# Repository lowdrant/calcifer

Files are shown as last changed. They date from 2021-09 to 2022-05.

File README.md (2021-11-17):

# calcifer
Raspberry Pi Talking Fireplace

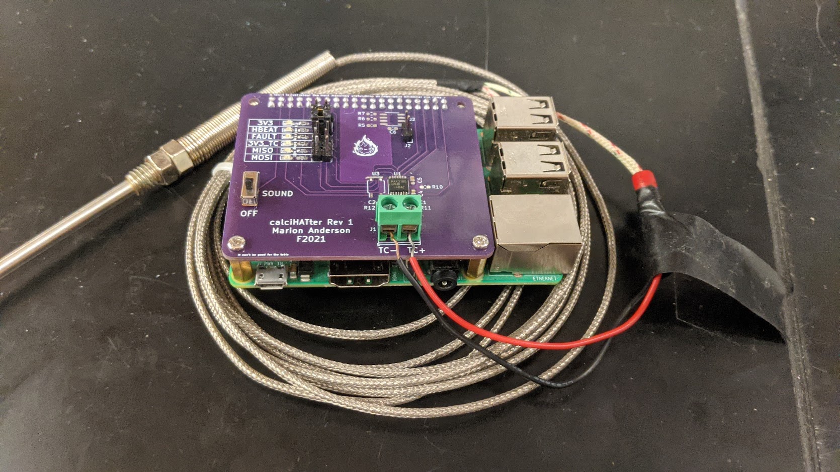
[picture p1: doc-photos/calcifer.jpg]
Calcifer


## Quick Start
1. Use AdaFruit's [MAX31856 breakout board](https://www.adafruit.com/product/3263) and a fire-resistant [thermocouple](https://www.adafruit.com/product/3245) setup.
2. Follow this [AdaFruit wiring guide](https://learn.adafruit.com/adafruit-max31856-thermocouple-amplifier/python-circuitpython) and connect `DRDY` to `Board D27` and `FAULT` to `Board D20`
3. Put the thermocouple in your fireplace
4. Connect a speaker to the RPI headphone jack
5. Run the following in the terminal:
```
> git clone https://github.com/lowdrant/calcifer.git
> sudo apt install python3-pip           # skip if pip3 installed
> cd calcifer
> ./install.sh                           # install dependencies
> sudo ./boot-setup.sh ADAFRUIT          # setup calcifer to run at boot (daemon)
> sudo systemctl start calcifer.service  # start daemon
> journatlctl -f -u calcifer.service     # stream log output
```

### Using with calciHATter PCB
calciHATter Pi HAT wiring is stored in the CALCIHATTER section of [calcifer.ini](calcifer.ini). After dependencies are installed, you only need to configure which config section Calcifer uses.
```
> sudo ./boot-setup.sh CALCIHATTER
> sudo systemctl restart calcifer.service
```

## Adding Sounds
Add .wav files to the [sounds/](sounds/) directory to add sounds for Calcifer. Calcifer plays a random .wav file from [sounds/](sounds/) when it detects a fire has started. This ensures Calcifer only plays a sound once rather than playing sounds constantly while a fire is going.

## Customizating Behavior and Pinout
[calcifer.ini](calcifer.ini) can be edited to configure entire hardware pinout and some program logic. It is parsed using Python3's `ConfigParser` object. After editing the config section the Calcifer daemon is using, run
```
> sudo systemctl restart calcifer.service
```
to reinitalize Calcifer with the new configuration. Since the config _section_ isn't changing, there's no need to resetup the daemon.

To change configuration sections (e.g. from ADAFRUIT to CALCIHATTER), run
```
> sudo ./boot-setup.sh <your-section>
```

### GPIO Configuration
GPIO values need to be of the form `board.XX` as if they are commands in a Python script because [calcifer.py](calcifer.py) uses `eval(<param>)` to configure GPIO objects. Look into CircuitPython for more details.

| Field | Desc | Example | Notes |
| --- | --- | --- | --- |
| spi | Amplifier SPI bus | board.SPI() | RPi SPI busses are weirdly specific |
| cs | Amplifier chip select | board.D22 | Digital Output |
| drdy | Amplifier data ready pin | board.D27 | Digital Input |
| tc_fault | Amplifier fault pin | board.D3 | Digital Input |
| tc_reset | Amplifier power switch pin | board.D26 | Digital Output |
| soundswitch | Toggle sound playing | board.D2 | Digital Input; play sound if high |
| hbeat | Heartbeat LED | board.D21 | Digital Output |
| fault | Fault indicator LED | board.D20 | Digital Output |

### Temperature Logic
Configure temperature sensor type, active/inactive temperature thresholds, and data reading frequency. `thresh` and `off_thresh` introduce hysterisis

| Field | Desc | Example | Notes |
| --- | --- | --- | --- |
| tctype | Thermocouple type | K | `adafruit_max31856.ThermocoupleType` |
| thresh | threshold for fire-on state | 100 | degC float |
| off_thresh | threshold for fire-off state | 50 | degC float; must be less than thresh |
| T_read | sample period in fire-off state | 1 | seconds |
| T_going | sample period in fire-on state  | 10 | seconds |

### Misc Behavior
This does not affect the user experience.
| Field | Desc | Example | Notes |
| --- | --- | --- | --- |
| host | Host for daemon stop command | 127.0.0.1 | host must be RPi |
| port | Port for daemon stop command | 10000 | |
| loglevel | log level to stdout | DEBUG | logging library value |
| drdy_count_timeout | Timeout for amp power cycle  | 3 | int |
| T_hbeat | Heartbeat period | 2 | seconds |

## Design Overview
### Hardware
The calciHATter PCB conforms to the Raspberry Pi HAT standard. It is a bare-bones PCB that allows a Pi to interface with the MAX31856 over SPI, a sound switch for enabling/disabling Calcifer, debug LEDs, and the configuration EEPROM. Its documentation, fabrication files, and bill of materials can be found in [calciHATter/](calciHATter/). It was designed in KiCAD. I do not provide a means to program the HAT EEPROM with pinout information.

### Software
The Calcifer daemon simply calls [calcifer.py](calcifer.py) with appropriate command line arguments.
[boot-setup.sh](boot-setup.sh) provides a CLI to automatically configure `calcifer.service` for SystemD.

Calcifer program logic is packaged as an object inside a CLI script to run the Calcifer mainloop in a clean, stateful way while also providing a basic testing/characterization interface for thermocouple evaluation and debugging.

The Calcifer object uses 3 threads in its mainloop
1. `_run`, which measures temperature and plays sound if fire goes from off to on
2. `_hbeat`, which blinks the heartbeat LED
3. `_listen`, which listens for a shutdown command on `host:port` and joins the mainllop threads on receipt of said shutdown command

### Fixing Sound Issues
Some PyGame dependencies need to be built from source (namely LibSDL2) for unknown reasons. `install.sh` should handle this, but if you are still getting sound issues, run the below to install the dependencies directly.
```
> ./install-pygame-deps.sh
```

## Author
Marion Anderson - [lmanderson42@gmail.com](mailto:lmanderson42@gmail.com)

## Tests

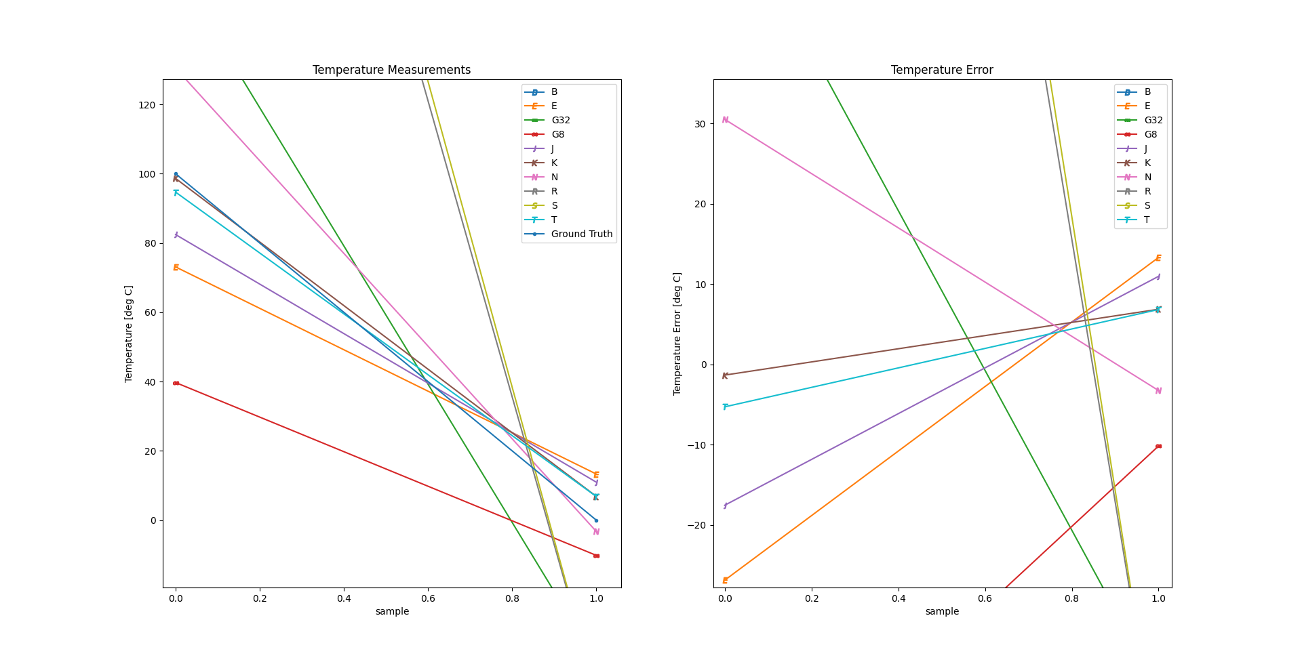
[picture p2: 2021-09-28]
tc-characterization.png

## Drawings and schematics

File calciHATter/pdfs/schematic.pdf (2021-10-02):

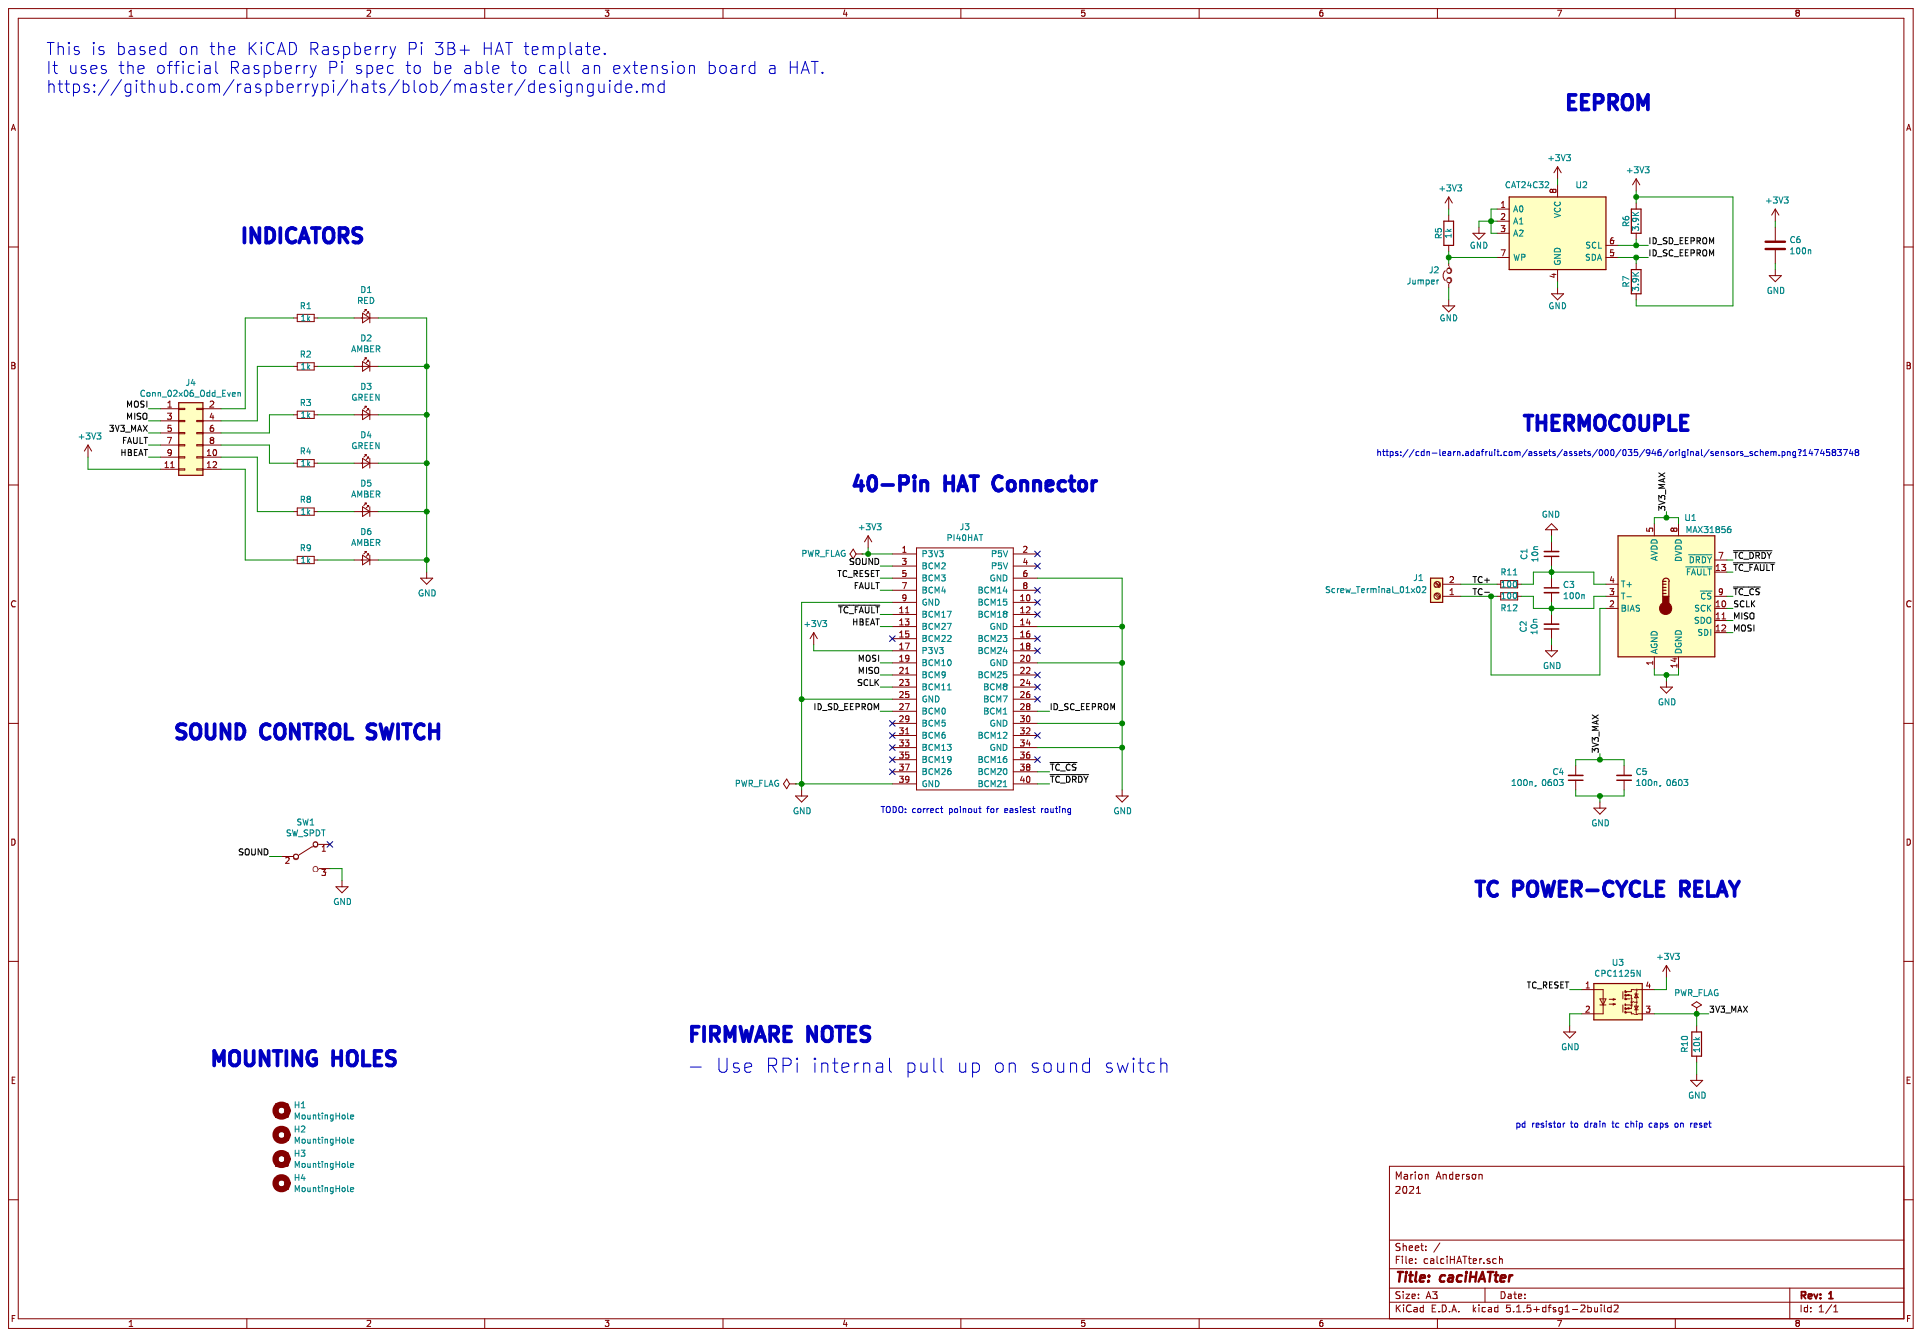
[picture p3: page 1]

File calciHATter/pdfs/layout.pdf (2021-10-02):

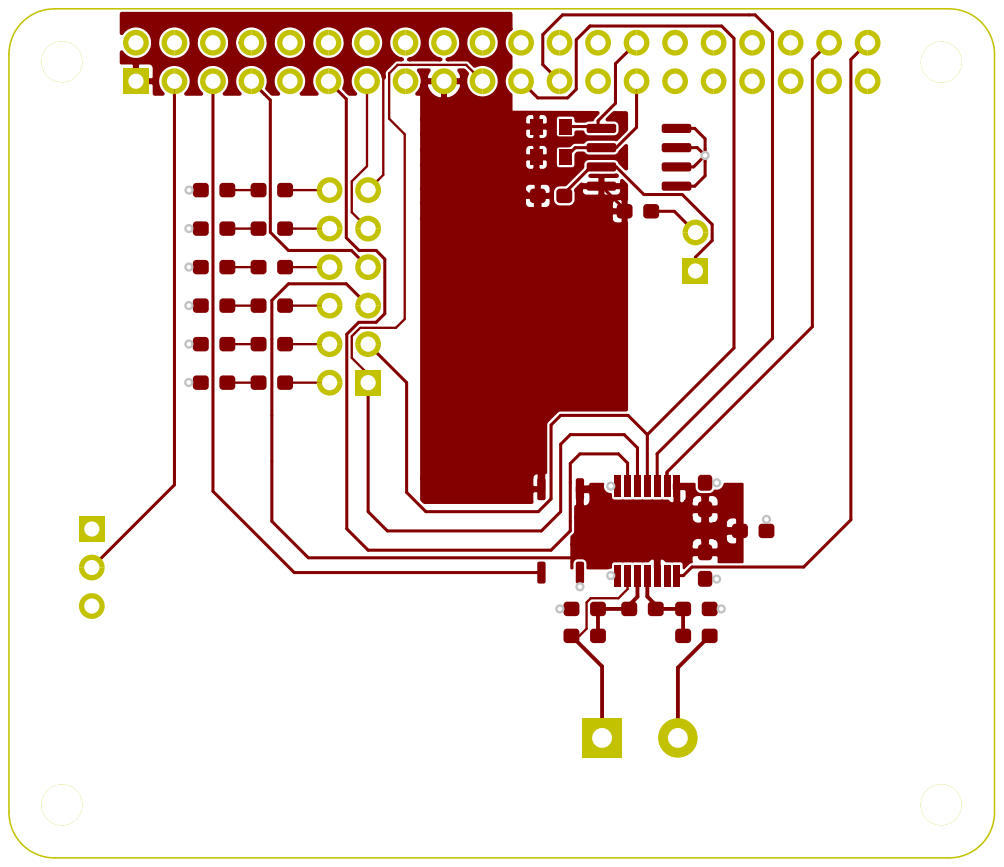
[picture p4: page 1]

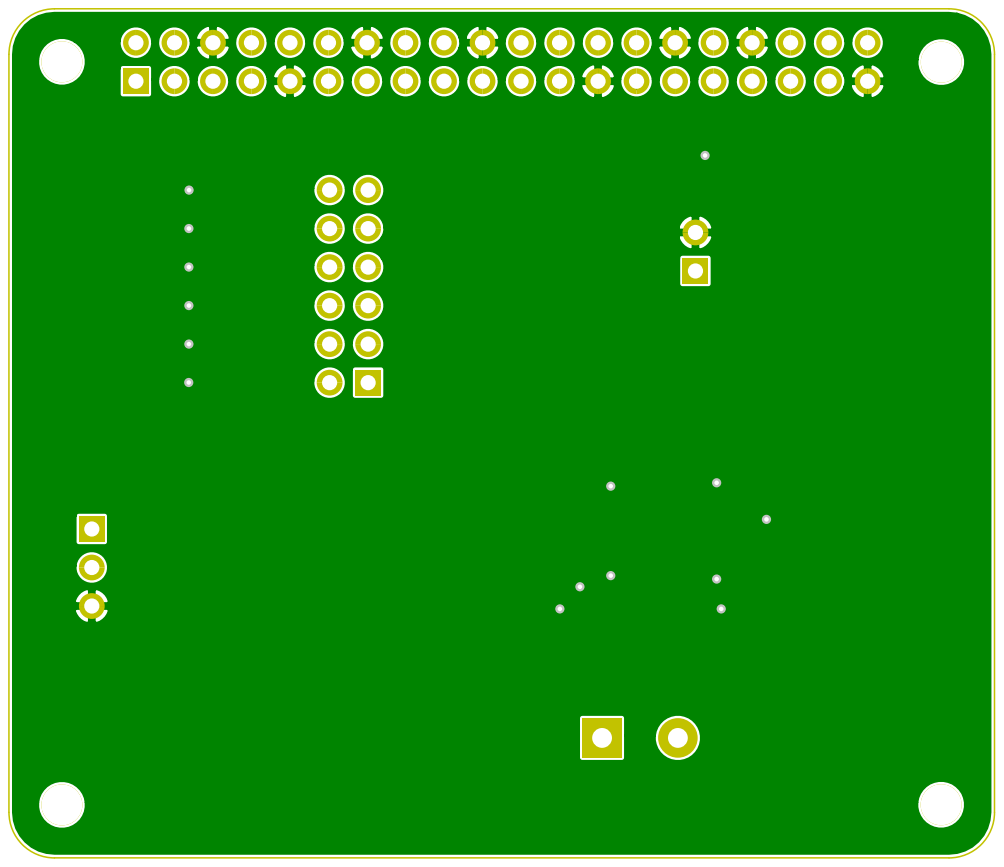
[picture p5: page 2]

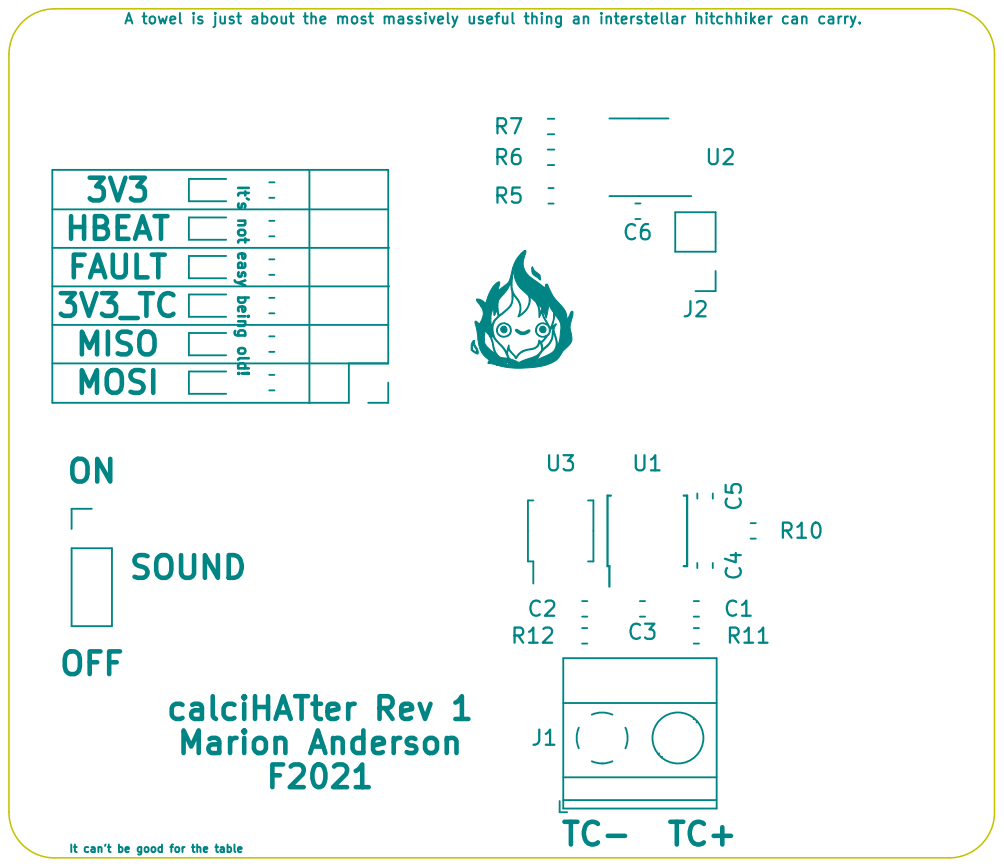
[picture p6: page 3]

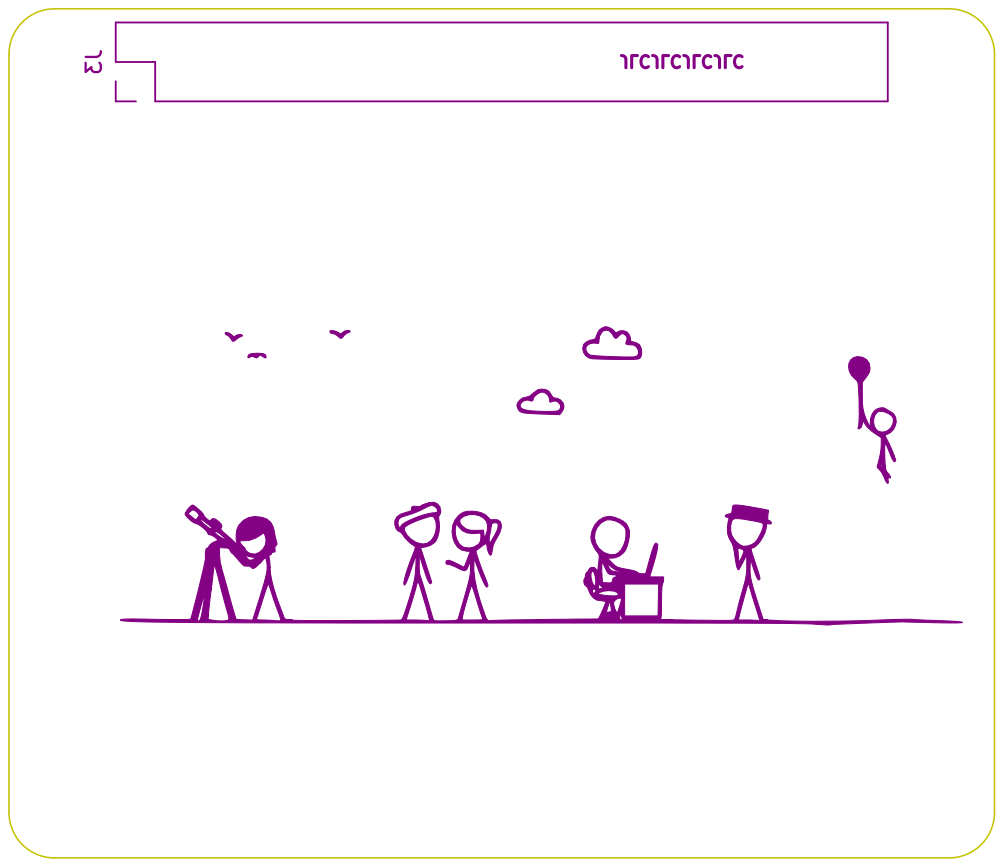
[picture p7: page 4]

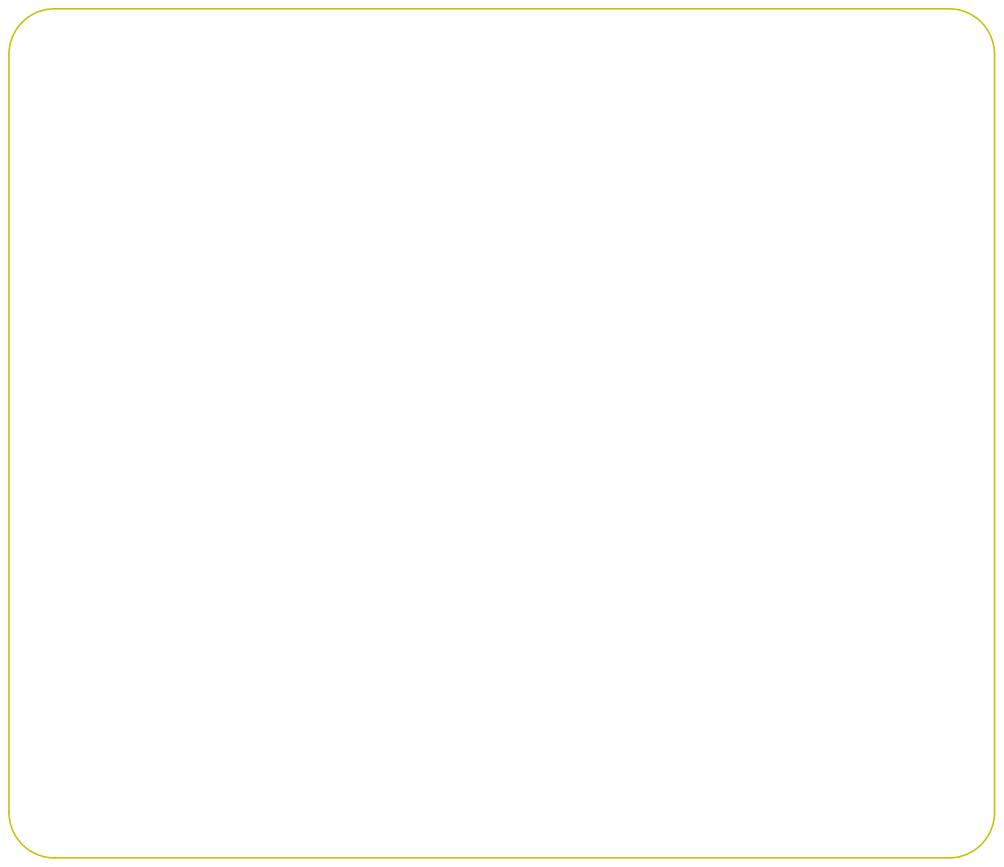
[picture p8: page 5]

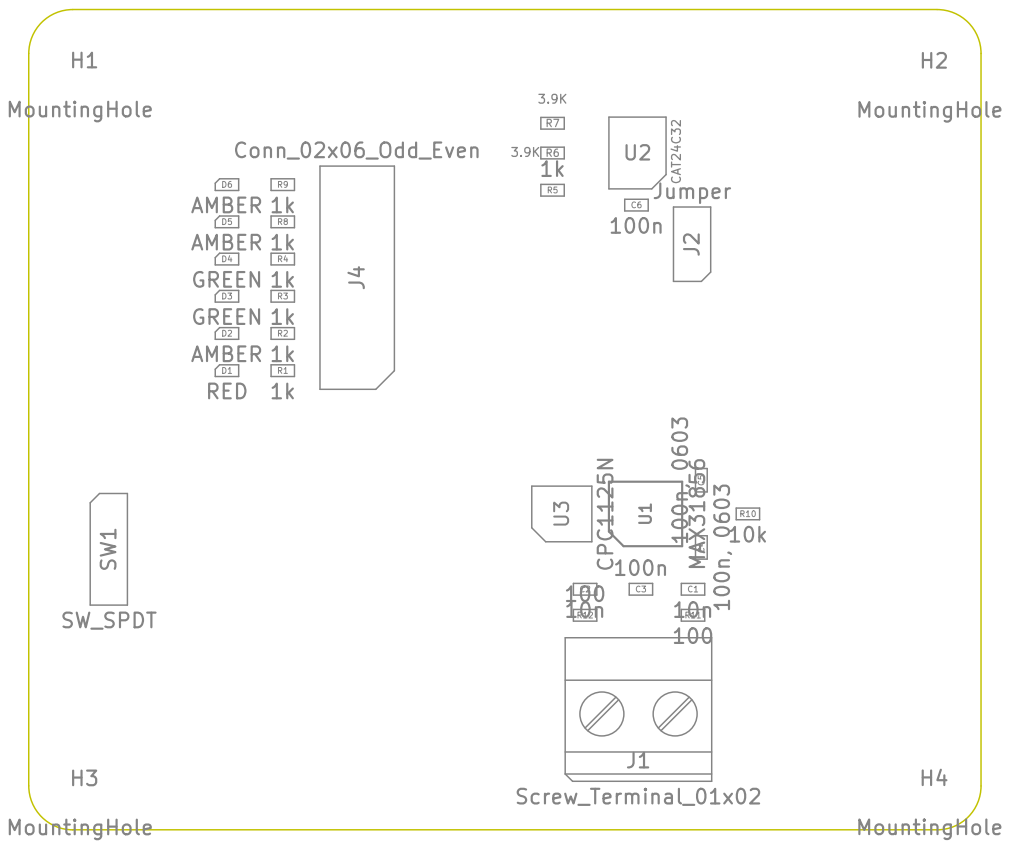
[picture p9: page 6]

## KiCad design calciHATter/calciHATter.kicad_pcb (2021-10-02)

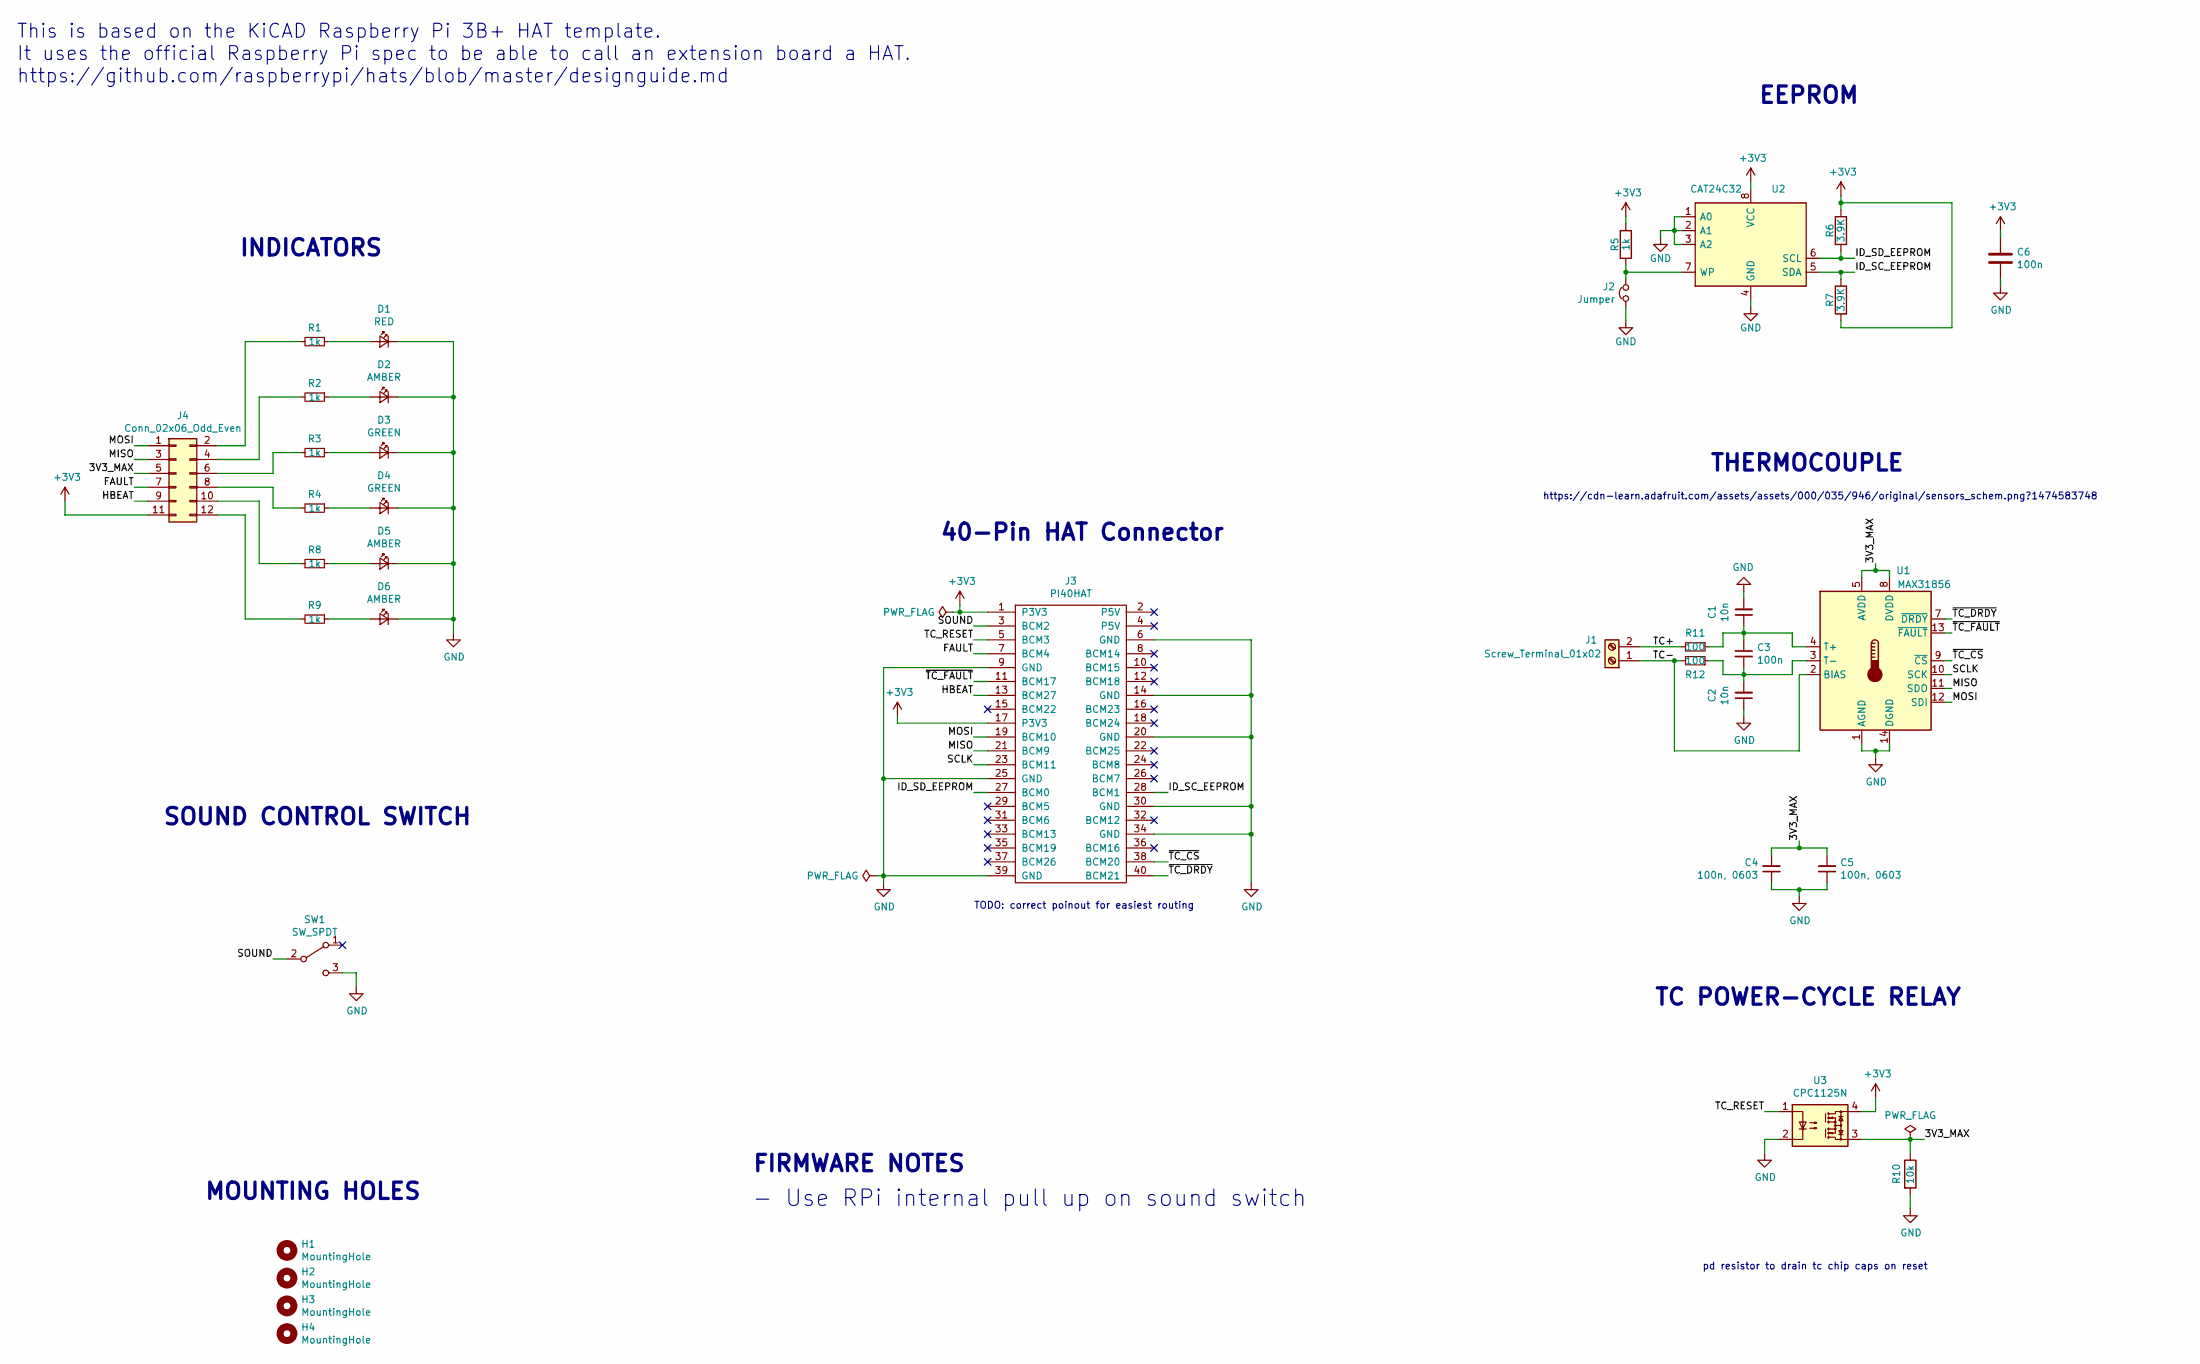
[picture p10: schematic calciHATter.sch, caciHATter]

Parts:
C1, C2: 10n; C_0603_1608Metric_Pad1.05x0.95mm_HandSolder
C3, C6: 100n; C_0603_1608Metric_Pad1.05x0.95mm_HandSolder
C4, C5: 100n, 0603; C_0603_1608Metric_Pad1.05x0.95mm_HandSolder
D1: RED; LED_0603_1608Metric_Pad1.05x0.95mm_HandSolder
D2, D5, D6: AMBER; LED_0603_1608Metric_Pad1.05x0.95mm_HandSolder
D3, D4: GREEN; LED_0603_1608Metric_Pad1.05x0.95mm_HandSolder
H1, H2, H3, H4: MountingHole; MountingHole_2.7mm_M2.5_DIN965
J1: Screw_Terminal_01x02; TerminalBlock_Phoenix_MKDS-1,5-2_1x02_P5.00mm_Horizontal
J2: Jumper; PinHeader_1x02_P2.54mm_Vertical
J3: PI40HAT; PinSocket_2x20_P2.54mm_Vertical
J4: Conn_02x06_Odd_Even; PinHeader_2x06_P2.54mm_Vertical
R1, R2, R3, R4, R5, R8, R9: 1k; R_0603_1608Metric_Pad1.05x0.95mm_HandSolder
R6, R7: 3.9K; R_0603_1608Metric_Pad0.84x1.00mm_HandSolder
R10: 10k; R_0603_1608Metric_Pad1.05x0.95mm_HandSolder
R11, R12: 100; R_0603_1608Metric_Pad1.05x0.95mm_HandSolder
SW1: SW_SPDT; PinHeader_1x03_P2.54mm_Vertical
U1: MAX31856; TSSOP-14_4.4x5mm_P0.65mm
U2: CAT24C32; SOIC-8_3.9x4.9mm_P1.27mm
U3: CPC1125N; SOP-4_3.8x4.1mm_P2.54mm

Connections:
+3V3: C6.1, J3.1 (P3V3), J3.17 (P3V3), J4.11, R5.2, R6.2, R7.2, U2.8 (VCC), U3.4
/3V3_MAX: C4.2, C5.2, J4.5, R10.1, U1.5 (AVDD), U1.8 (DVDD), U3.3
/FAULT: J3.7 (BCM4), J4.7
/HBEAT: J3.13 (BCM27), J4.9
/ID_SC_EEPROM: J3.28 (BCM1), R7.1, U2.5 (SDA)
/ID_SD_EEPROM: J3.27 (BCM0), R6.1, U2.6 (SCL)
/MISO: J3.21 (BCM9), J4.3, U1.11 (SDO)
/MOSI: J3.19 (BCM10), J4.1, U1.12 (SDI)
/SCLK: J3.23 (BCM11), U1.10 (SCK)
/SOUND: J3.3 (BCM2), SW1.2 (B)
/TC+: J1.2, R11.2
/TC-: J1.1, R12.2, U1.2 (BIAS)
/TC_RESET: J3.5 (BCM3), U3.1
/~TC_CS: J3.38 (BCM20), U1.9 (~CS)
/~TC_DRDY: J3.40 (BCM21), U1.7 (~DRDY)
/~TC_FAULT: J3.11 (BCM17), U1.13 (~FAULT)
GND: C1.2, C2.1, C4.1, C5.1, C6.2, D1.1 (K), D2.1 (K), D3.1 (K), D4.1 (K), D5.1 (K), D6.1 (K), J2.2, J3.6 (GND), J3.9 (GND), J3.14 (GND), J3.20 (GND), J3.25 (GND), J3.30 (GND), J3.34 (GND), J3.39 (GND), R10.2, SW1.3 (C), U1.1 (AGND), U1.14 (DGND), U2.1 (A0), U2.2 (A1), U2.3 (A2), U2.4 (GND), U3.2
unnamed: C1.1, C3.1, R11.1, U1.4 (T+)
unnamed: C2.2, C3.2, R12.1, U1.3 (T-)
unnamed: D1.2 (A), R1.1
unnamed: D2.2 (A), R2.1
unnamed: D3.2 (A), R3.1
unnamed: D4.2 (A), R4.1
unnamed: D5.2 (A), R8.1
unnamed: D6.2 (A), R9.1
unnamed: J2.1, R5.1, U2.7 (WP)
unnamed: J4.2, R1.2
unnamed: J4.4, R2.2
unnamed: J4.6, R3.2
unnamed: J4.8, R4.2
unnamed: J4.10, R8.2
unnamed: J4.12, R9.2

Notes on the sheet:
This is based on the KiCAD Raspberry Pi 3B+ HAT template. It uses the official Raspberry Pi spec to be able to call an extension board a HAT. https://github.com/raspberrypi/hats/blob/master/designguide.md
MOUNTING HOLES
40-Pin HAT Connector
THERMOCOUPLE
EEPROM
INDICATORS
TC POWER-CYCLE RELAY
TODO: correct poinout for easiest routing
pd resistor to drain tc chip caps on reset
https://cdn-learn.adafruit.com/assets/assets/000/035/946/original/sensors_schem.png?1474583748
SOUND CONTROL SWITCH
- Use RPi internal pull up on sound switch
FIRMWARE NOTES

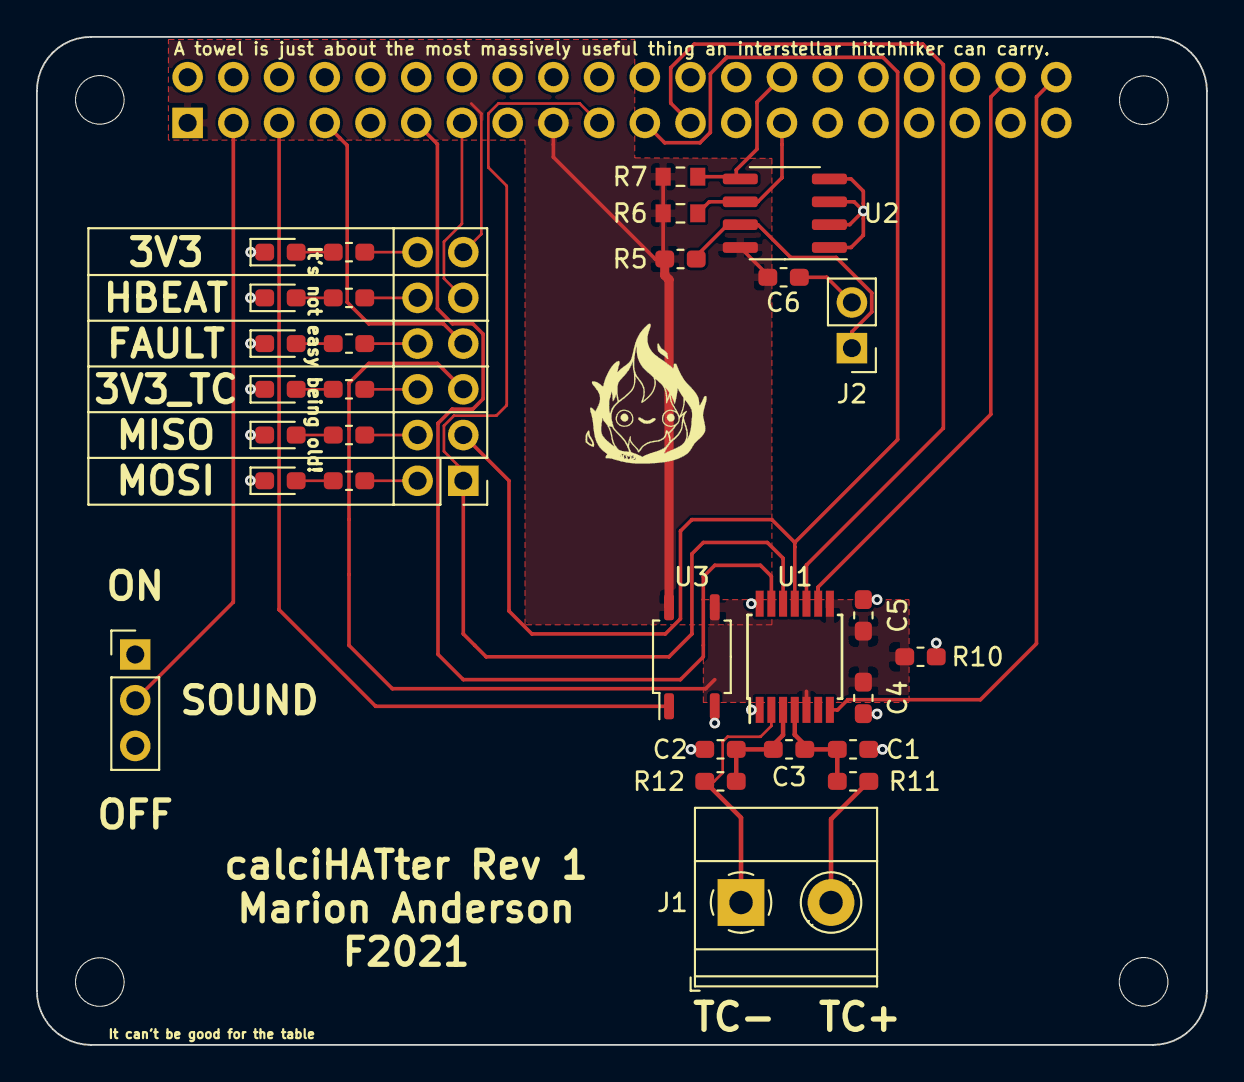
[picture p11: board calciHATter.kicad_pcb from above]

Board: 2 copper layers, 65.0 x 56.0 mm, 36 parts (1 on the bottom side), 32 nets.

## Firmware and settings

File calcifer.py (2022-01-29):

#!/usr/bin/env python3
"""
Raspberry Pi talking fireplace execution code. Provides temperature
measurement functions and class for executing Calcifer behavior in stateful
manner.

Author: Marion Anderson
"""

__all__ = ['Calcifer, temp_all', 'gen_tc_types']

from argparse import ArgumentError, ArgumentParser
from configparser import ConfigParser
from logging import (CRITICAL, DEBUG, ERROR, INFO, WARNING, Formatter, Logger,
                     StreamHandler)
from pathlib import Path
from os import environ
from random import randint
from socket import AF_INET, SOCK_STREAM
from socket import error as sock_error
from socket import socket
from sys import stdout
from threading import Thread
from time import sleep, time

import board
from digitalio import Direction as dioDirection
from digitalio import Pull as dioPull
from digitalio import DigitalInOut as dioDigitalInOut
from adafruit_max31856 import MAX31856, ThermocoupleType


def gen_tc_types():
    """Generate allowed thermocouple types using the attributes of
    ThermocoupleType.

    Returns
    -------
    List of strings
        List of thermocouple type attribute names stored as strings.

    Notes
    -----
    Thermocouple types are 1-3 letters, all caps, attribute names of
    ThermocoupleType. So we can use dir(ThermocoupleType) and skip anything
    with an underscore to only keep the allowable thermocouple types.

    See Also
    --------
    `adafruit_max31856.ThermocoupleType`
    """
    return [str(v) for v in dir(ThermocoupleType) if '_' not in v]


def temp_all(spi, cs):
    """Measure thermocouple temperature for all thermocouple types.

    Parameters
    ----------
    spi : board.SPI object
        spi parameter for MAX31856 object
    cs : dioDigitalInOut object
        cs param for MAX31856 object

    Returns
    -------
    dict
        Temperature measurements keyed with thermocouple type

    See Also
    -------
    adafruit_max31856.MAX31856
    adafruit_max31856.ThermocoupleType
    """
    assert cs.direction == dioDirection.OUTPUT, 'cs must be output'
    outdict = {}
    for k in gen_tc_types():
        tctype = eval(f'ThermocoupleType.{k}')
        tc = MAX31856(spi, cs, thermocouple_type=tctype)
        outdict.update({k: tc.temperature})
    return outdict


class Calcifer(object):
    """
    Stateful mainloop for Calcifer talking fireplace sensing and actuation.
    Uses threads to run temperature checker, heartbeat, and listen for
    shutdown command.

    States
    ------
    go         - Mainloop state. True for running, False for shutdown
    fire_going - Fire detected state. True if fire detected, False otherwise
    thresh     - Celsius threshold for fire off to fire on
    off_thresh - Celsius threshold for fire on to fire off


    Threading
    ---------
    host        - IP to listen for shutdown command on
    port        - port to listen for shutdown command on
    sock        - socket listening for shutdown command
    runthread   - mainloop thread - performs temperature checking and sound playing
    sockthread  - thread for socket listening
    hbeatthread - thread for blinking heartbeat LED

    Timing
    ------
    T_read             - Frequency of temperature reading when fire off
    T_going            - Frequency of temperature reading when fire going
    T_hbeat            - Heartbeat LED frequency
    tc_reset_delay     - Delay before repowering TC amp
    drdy_count         - Number of times TC drdy pin hasn't been ready
    drdy_count_timeout - max drdy_count before power cycling TC

    GPIO Pins
    ---------
    cs          - TC amplifier chip select pins
    drdy        - TC amplifier data ready pin
    hbeat       - heartbeat LED pin
    tc_reset    - TC power supply relay pin
    fault       - fault LED
    soundswitch - sound control pin input
    """
    def  __init__(self, fnconf=None, section='DEFAULT', **kwargs):
        # Config Setup
        if fnconf is None:
            fnconf = Path(__file__).resolve().parent / 'calcifer.ini'
        self.fnconf = fnconf  # for --bg cli simply access
        conf = ConfigParser()
        try:
            conf.read(fnconf)
        except OSError as e:
            print('os error on conf read')

        # Overwrite Config File
        for k, v in kwargs.items():
            conf[section][k] = v

        # Read Config Params
        # - before major setup so errors avoid consuming resources
        # logging
        self.loglevel = eval(conf[section]['loglevel'])
        self._configlogger()
        # timing params
        self.T_read = float(conf[section]['T_read'])
        self.T_going = float(conf[section]['T_going'])
        self.T_hbeat = float(conf[section]['T_hbeat'])/2  # half for on/off cycle
        self.tc_reset_delay = float(conf[section]['tc_reset_delay'])
        self.drdy_count = 0  # timeout counter
        self.drdy_count_timeout = int(conf[section]['drdy_count_timeout'])
        # hysterysis temperature state thresholds
        self.thresh = float(conf[section]['thresh'])
        self.off_thresh = float(conf[section]['off_thresh'])
        # sound files
        self.soundpath = Path(__file__).resolve().parent / 'sounds'
        self.soundfns = list(self.soundpath.iterdir())
        # socket connections
        self.host = conf[section]['host']
        self.port = int(conf[section]['port'])
        # thermocouple
        self._tctype_str = conf[section]['tctype']  # for debugging
        self.tctype =  eval(f'ThermocoupleType.{conf[section]["tctype"]}')

        # Internal Setup
        self._buflen = 2  # buffer length
        self.clr_tempbuf()  # set self.tempbuf, self.bufndx
        self.fire_going = False
        self.runthread = None
        self.sockthread = None
        self.hbeatthread = None
        self.go = False

        # Thermocouple Setup
        self.spi = eval(conf[section]['spi'])
        self.cs = dioDigitalInOut(eval(conf[section]['cs']))
        self.cs.direction = dioDirection.OUTPUT
        self.drdy = dioDigitalInOut(eval(conf[section]['drdy']))
        self.drdy.direction = dioDirection.INPUT
        self.drdy.pull = dioPull.DOWN
        self._configtc()
        self.tc_fault = dioDigitalInOut(eval(conf[section]['tc_fault']))
        self.tc_fault.direction = dioDirection.INPUT

        # TC Reset Relay Setup
        self.tc_reset = dioDigitalInOut(eval(conf[section]['tc_reset']))
        self.tc_reset.direction = dioDirection.OUTPUT
        self.tc_reset.value = 0

        # Indicator LED Setup
        self.hbeat = dioDigitalInOut(eval(conf[section]['hbeat']))
        self.hbeat.direction = dioDirection.OUTPUT
        self.hbeat.value = 0
        self.fault = dioDigitalInOut(eval(conf[section]['fault']))
        self.fault.direction = dioDirection.OUTPUT
        self.fault.value = 0

        # Sound Control Switch Setup
        self.soundswitch = dioDigitalInOut(eval(conf[section]['soundswitch']))
        self.soundswitch.direction = dioDirection.INPUT
        self.soundswitch.pull = dioPull.UP

        # Socket Setup
        self.sock = socket(AF_INET, SOCK_STREAM)

        # Log
        self.logger.debug(f'Calcifer setup complete. Configuration:{dict(conf[section])}')

    def _configtc(self):
        """Update `self.tc` with current spi, cs, tctype params.

        Notes
        -----
        Uses SPI bus, so can only be called after SPI bus setup
        """
        self.tc = MAX31856(self.spi, self.cs, thermocouple_type=self.tctype)

    def _configlogger(self):
        """Update `self.logger` with current loglevel param."""
        self.logger = Logger(__file__)
        handler = StreamHandler(stdout)
        handler.setLevel(self.loglevel)
        formatter = Formatter('%(levelname)s - %(message)s')
        handler.setFormatter(formatter)
        self.logger.addHandler(handler)

    def set_tc_type(self, tctype):
        """Update thermocouple type.

        Parameters
        ----------
        tctype : str
            Thermocouple type being read; attribute of `ThermocoupleType`

        See Also
        --------
        adafruit_max31856.ThermocoupleType
        """
        self._tctypestr = tctype
        self.tctype = eval(f'ThermocoupleType.{tctype}')
        self._configtc()

    def set_loglevel(self, loglevel):
        """Change logger loglevel

        Parameters
        ----------
        loglevel : str/loglevel
            logging library loglevel. Choices: 'DEBUG', 'INFO', 'WARNING',
                                               'ERROR', 'CRITICAL'

        See Also
        --------
        logging
        logging.Logger
        """
        if str(loglevel) not in ('DEBUG','INFO','WARNING','ERROR','CRITICAL'):
            self.logger.error(f'invalid loglevel:{loglevel}')
            return
        self.loglevel = eval(loglevel)
        self._configlogger()

    @property
    def temperature(self):
        """Read sensor temperature"""
        return self.tc.temperature

    def clr_tempbuf(self):
        """Fill temperature buffer with zeros & reset buffer index."""
        self.tempbuf = [0 for i in range(self._buflen)]
        self.bufndx = 0

    def update_tempbuf(self):
        """Update self.tempbuf circular buffer."""
        # check that data is ready to be read
        drdyval = self.drdy.value
        if drdyval:
            self.bufndx = (self.bufndx + 1) % self._buflen  # current data ndx
            self.tempbuf[self.bufndx] = self.temperature
            self.drdy_count = 0  # reset timeout counter
        self.logger.debug(f'drdy before read:{self.drdy.value}')
        self.logger.debug(f'tc_fault before read:{self.tc_fault.value}')
        # timeout condition
        self.logger.debug(f'drdy_count:{self.drdy_count}')
        if self.drdy_count < self.drdy_count_timeout and self.tc_fault.value==1:
            self.fault.value = 0
        else:
            self.fault.value = 1
        self.logger.debug(f'fault:{self.fault.value}')
        if self.drdy_count > self.drdy_count_timeout:
            self.logger.critical(f'drdy timed out; power cycling max')
            self.powercycle_max()
        if self.tc_fault.value:
            self.logger.critical(f'tc_fault:{self.tc_fault.value}')

        self.drdy_count += 1  # increment timeout counter every time

    def soundbyte(self):
        """Play random file from `sounds/` directory."""
        n = randint(0, len(self.soundfns)-1)
        fn = self.soundfns[n]
        # https://github.com/TaylorSMarks/playsound/issues/16
        mixer.init()  # only have mixer going when playing
        mixer.music.load(fn)
        self.logger.debug(f'playing {fn}')
        tstart = time()
        mixer.music.play()
        while mixer.music.get_busy():  # TODO: infinite loop
            self.logger.debug(f'sound playing time: {(time()-tstart):.1f}s')
            sleep(1)
        mixer.quit()  # stop mixer to avoid underrun
    def _run(self):
        """Calcifer mainloop. Controlled by `self.go` attribute."""
        while self.go:
            try:
                if self.tc_fault.value == 0:
                    self.logger.critical(f'tc_fault pin low')

                self.update_tempbuf()
                self.logger.debug(f'tempbuf:{self.tempbuf}')
                self.logger.debug(f'fire_going:{self.fire_going}')

                if self.fire_going:
                    if self.tempbuf[self.bufndx] < self.off_thresh:
                        self.fire_going = False
                        self.logger.info(f'Fire no longer going, tempbuf:{self.tempbuf}')
                    sleep(self.T_going)

                else:
                    if self.tempbuf[self.bufndx] > self.thresh:
                        # TODO: log thresh cross
                        if self.soundswitch.value:
                            self.logger.info('soundswitch high; playing sound')
                            self.soundbyte()
                        else:
                            self.logger.info('soundswitch low; not playing sound')
                        self.fire_going = True
                        self.logger.info(f'Fire going, tempbuf:{self.tempbuf}')
                    sleep(self.T_read)
            except Exception as e:
                self._errlog(e)

        self.logger.debug(f'run thread exited. go:{self.go}')
        self.logger.info('Calcifer program ended.')

    def _listen(self):
        """Shutoff command listener thread. Controlled by `self.go` attribute."""
        while self.go:
            try:
                self.sock.listen()
                conn, addr = self.sock.accept()
                data = conn.recv(128).decode('utf-8')
                # TODO: log received connections
                if data == 'off':
                    self.go = False
                    self.sock.close()
                    self.logger.info('Shutoff signal recieved. Shutting down...')
                else:
                    self.logger.warning(f'Socket connection sent {data} rather than off')
                    self.fault.value = 1  # turn on fault led to alert user
                self.logger.debug(
                    f'socket connection; conn:{conn} addr:{addr} data:{data} go:{self.go}'
                )
            except Exception as e:
                self._errlog(e)
        self.logger.debug(f'listen thread exited. go:{self.go}')

    def _hbeat(self):
        """Heartbeat LED execution thread. Controlled by `self.go` attribute."""
        while self.go:
            self.hbeat.value = not self.hbeat.value if (self.T_hbeat>0) else 0  # no hbeat case
            sleep(self.T_hbeat)
        self.hbeat.hbeat = 0  # turn off led when ending program
        self.logger.debug(f'hbeat thread exited. go:{self.go}')

    def start(self):
        """Start Calcifer mainloop thread."""
        if self.go:
            self.logger.error('start called but go already True')
            return
        try:
            self.sock.bind(('127.0.0.1', self.port))
        except sock_error as e:
            print(e)
            self.logger.error(f'start called but 127.0.0.1:{self.port} already in use')
            return
        self.go = True
        # calcifer thread
        self.runthread = Thread(target=self._run, args=())
        self.runthread.daemon = True
        # shutoff command socket thread
        self.sockthread = Thread(target=self._listen, args=())
        self.sockthread.daemon = True
        # heartbeat thread
        self.hbeatthread = Thread(target=self._hbeat, args=())
        self.hbeatthread.daemon = True
        # start threads
        self.runthread.start()
        self.sockthread.start()
        self.hbeatthread.start()

    def _wrapup(self):
        """Release resources + turn off relay/leds."""
        self.hbeat.value = 0
        self.tc_reset.value = 0
        try:
            self.sock.close()
        except sock_error as e:
            logger.error('Failed to close socket')

    def join(self):
        """Calcifer instance equivalent to `thread.join`"""
        try:
            self.hbeatthread.join()
        except Exception as e:
            pass
        try:
            self.sockthread.join()
        except Exception as e:
            pass
        try:
            self.runthread.join()
        except Exception as e:
            pass
        self.logger.debug('All threads have joined')
        self._wrapup()

    def stop(self, join=False):
        """Stop Calcifer mainloop thread.

        Parameters
        ----------
        join : bool, optional
            Whether or not to join instance's run threads, by default False
        """
        # use socket to enforce
        with socket(AF_INET, SOCK_STREAM) as sock:
            sock.connect( (self.host, self.port) )
            sock.sendall( b'off' )
        if join:
            self.join()

    def powercycle_max(self):
        """Power cycle max chip using relay on relay pin."""
        self.tc_reset.value = True
        sleep(self.tc_reset_delay)  # TODO: empirically determined
        self.tc_reset.value = False
        self._configtc()  # call to ensure correct tc chip configuration
        sleep(self.tc_reset_delay)  # TODO: empirically determined

    def _errlog(e):
        """put error on logger

        Parameters
        ----------
        e : Exception
        """
        errstr = f'{e.__name__}: '
        if hasattr(e, args):
            errstr = errstr + ' '.join(e.args)
        self.logger.error(errstr)

parser = ArgumentParser('usage: Talking fireplace interface. ' +
                        'Also provides thermocouple characterization CLI')
parser.add_argument('--fnconf', type=str, default=None,
                    help='Conf file for thermocouple. Defaults to calcifer.ini')
parser.add_argument('--section', type=str, default='DEFAULT',
                    help='Conf file section to use for thermocouple.')
parser.add_argument('--characterize', action='store_true',
                    help='Thermocouple characterization interface.')
parser.add_argument('--oneshot', action='store_true',
                    help='Report a single temperature reading.')
parser.add_argument('--type', type=str, default=None, choices=gen_tc_types(),
                    help='Specify thermocouple type; overrides config file setting.')
parser.add_argument('--loglevel', type=str, default=None,
                    choices=['DEBUG', 'INFO', 'WARNING', 'ERROR', 'CRITICAL'],
                    help='Specify loglevel overriding config file setting.')
parser.add_argument('--run', action='store_true', help='Run Calcifer mainloop')
parser.add_argument('--bg', action='store_true', help='Run Calcifer mainloop in background.')
parser.add_argument('--stop', action='store_true', help='Stop Calcifer backgrounded mainloop')

if __name__ == '__main__':
    # prevent also underrun errors
    # https://raspberrypi.stackexchange.com/questions/83254/pygame-and-alsa-lib-error
    #environ['SDL_AUDIODRIVER'] = 'dsp'

    # parse arguments
    args = parser.parse_args()
    kwargs = {}
    if args.type is not None:  # set tc type after init for simplicity
        kwargs.update({'tctype':args.type})
    if args.loglevel is not None:
        kwargs.update({'loglevel':args.loglevel})
    job = Calcifer(fnconf=args.fnconf, section=args.section, **kwargs)

    if args.oneshot:
        print(f'{job._tctype_str}-type Temperature: {job.temperature}')

    if args.characterize:
        import matplotlib.pyplot as plt  # numerics only used here; import
        from numpy import asarray  # here to avoid slowing startup
        truetemp = []
        meastemp = []
        while True:
            inp = input('Reference Temperature (degC) (or \'quit\'): ')
            # exit cond
            if inp.lower() in ('q','quit','exit'):
                print('End characterization')
                break
            try:
                t = float(inp)
            # bad input
            except ValueError:
                print('Bad input')
                continue
            # temp reading
            else:
                truetemp.append(t)
                meastemp.append(temp_all(job.spi, job.cs))
        # reorder measurements into dict of lists
        meastemp_dict = {k:[] for k in meastemp[0].keys()}
        for m in meastemp:
            [meastemp_dict[k].append(v) for k,v in m.items()]
        meastemp = {k:asarray(v) for k,v in meastemp_dict.items()}
        errtemp = {k:v-truetemp for k,v in meastemp.items()}
        print('End computations')

        print('Plotting...')
        fig, ax = plt.subplots(ncols=2, num='tc-characterization')
        # Measurement Plot
        ax[0].set_title('Temperature Measurements')
        ax[0].set_ylabel('Temperature [deg C]')
        ax[0].set_xlabel('sample')
        for k,v in meastemp_dict.items():
            ax[0].plot(v, '-', label=f'{k}', marker=f'${k}$')
        # plot ground truth last for color matching b/t subplots
        ax[0].plot(truetemp, '.-', label='Ground Truth')
        ax[0].legend()

        # Error Plot
        ax[1].set_title('Temperature Error')
        ax[1].set_ylabel('Temperature Error [deg C]')
        ax[1].set_xlabel('sample')
        for k,v in errtemp.items():
            ax[1].plot(v, '-', label=f'{k}', marker=f'${k}$')
        ax[1].legend()

        plt.show()

    if args.bg:
        from subprocess import Popen  # subprocess only used here
        act = Path(__file__).resolve().parent / 'env/bin/activate'
        fn = Path(__file__).resolve()
        Popen(['python3', fn, f'--fnconf={job.fnconf}',
               f'--section={args.section}', f'--type={args.type}', '--run'])

    if args.run:
        # basic install check
        try:
            # https://github.com/TaylorSMarks/playsound/issues/16
            from pygame import mixer
        except Exception as e:
            print('Did you run `install-pygame-deps.sh`?')
            raise e
        # run job
        try:
            job.start()
            job.join()
        except (Exception, KeyboardInterrupt) as e:
            job.go = False
            if type(e) != KeyboardInterrupt:
                job.fault.value = 1  # turn on fault led
                job.logger.error(e)  # log error
                raise e
        finally:
            mixer.quit()

    if args.stop:
        job.stop(join=False)  # can't join; threads on diff Calcifer instance

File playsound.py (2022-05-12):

#!/usr/bin/env python3
"""
play arbitrary sound from Rpi
"""
if __name__ == '__main__':
    from argparse import ArgumentParser
    from pygame import mixer
    parser = ArgumentParser('Play arbitrary sound file from RPi')
    parser.add_argument('fn', type=str, help='sound file filename+path')
    args = parser.parse_args()
    mixer.init()
    mixer.music.load(args.fn)
    mixer.music.play()
    while mixer.music.get_busy():
        pass
    mixer.quit()

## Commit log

2021-06-10 started a HAT. not totally sure if it's worth the effort
    [calciHATter.kicad_pcb, calciHATter.sch]
2021-08-22 started temperature & thread inteface
2021-09-28 Switched to PyGame for sound
2021-09-29 Working socket-based thread killer. TODO: figure out why pygame isn't working
2021-09-29 added indicator led functionality
2021-09-29 added relay toggle delay to config file
2021-09-30 Added tc chip reset condition + more logging
    [calcifer.py]
2021-10-01 PCB placement to include indicators and toggle switch
    [calciHATter.kicad_pcb, calciHATter.sch]
2021-10-01 continued layout, some routing & pinout changes
    [calciHATter.kicad_pcb, calciHATter.sch]
2021-10-01 Finalized pinout, routing. TODO: cleanup+ERC
    [calciHATter.kicad_pcb, calciHATter.sch]
2021-10-02 finalized schematic+routing. need easter eggs and footprint checks
    [calciHATter.kicad_pcb, calciHATter.sch]
2021-10-02 release calciHATter rev 1 for fab
    [calciHATter.kicad_pcb, calciHATter.sch]
2021-10-03 config file now matches pcb pinout. installation cleanup
2021-11-13 added pcb net file
2021-11-17 pcb photo to readme
2022-01-28 corrected thermocouple fault detection gpio; more robust thread joining
    [calcifer.py]
2022-01-28 improved state logging; added fireplace params; maybe resolved also underrun bug
    [calcifer.py]
2022-01-29 corrected fault pin configuration; added socket fail-to-close error messages
    [calcifer.py]
